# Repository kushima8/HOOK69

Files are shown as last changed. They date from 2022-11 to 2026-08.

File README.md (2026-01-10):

# HOOK69
Keyboard that hooks up to LCD tablets

https://shop.yushakobo.jp/products/5657

FZYuu6GaUAAWrVO
FZYuvYvaIAIYb_v

## Build Guide

[ビルドガイド（日本語）](Documents/buildguide.md)
  
120px-Cc-by-nc-sa_icon svg

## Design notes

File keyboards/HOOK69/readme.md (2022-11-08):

# hook69

hook69

*A short description of the keyboard/project*

* Keyboard Maintainer: [kushima8](https://github.com/yourusername)
* Hardware Supported: *The PCBs, controllers supported*
* Hardware Availability: *Links to where you can find this hardware*

Make example for this keyboard (after setting up your build environment):

    make hook69:default

Flashing example for this keyboard:

    make hook69:default:flash

See the [build environment setup](https://docs.qmk.fm/#/getting_started_build_tools) and the [make instructions](https://docs.qmk.fm/#/getting_started_make_guide) for more information. Brand new to QMK? Start with our [Complete Newbs Guide](https://docs.qmk.fm/#/newbs).

## Bootloader

Enter the bootloader in 3 ways:

* **Bootmagic reset**: Hold down the key at (0,0) in the matrix (usually the top left key or Escape) and plug in the keyboard
* **Physical reset button**: Briefly press the button on the back of the PCB - some may have pads you must short instead
* **Keycode in layout**: Press the key mapped to `RESET` if it is available

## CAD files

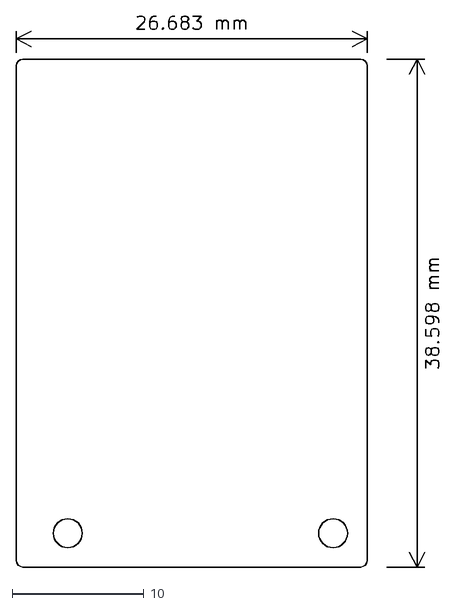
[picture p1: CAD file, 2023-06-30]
Plate/hook69_plate.dxf
32.1 x 41.9

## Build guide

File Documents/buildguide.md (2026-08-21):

# HOOK69 ビルドガイド

## ご購入前にお読みください

本製品をご購入いただいた時点で、下記「譲渡・再販について」の内容にご同意いただいたものとみなします。

### 譲渡・再販について

BOOTHや遊舎工房など、作者本人が販売または委託している場所以外で購入された場合、同梱品の不足や不良品への対応など、各種サポートをいたしかねます。  
そのため、以下のとおりお願いしております。

1. 本製品（完成品・未完成品・付属部品を問わず）を、ネットオークション、フリマサービス、その他の方法により第三者へ有償で譲渡することを禁止します。
2. 本項に反する行為を確認した場合、以後の販売をお断りする場合があります。

## はじめに
このたびはご購入いただきありがとうございます。  
本製品は組み立てが必要なキットです。  

作成にあたり不明点や疑問点などがありましたら、作者の[Twitterアカウント](https://twitter.com/kushima8)までご連絡ください。  
Twitter以外で連絡を頂いても対応が厳しいです。  
FF外からのリプライは通知オフにしており気づかない場合がこざいますご了承ください。  
それとDiscordのコミュニティなどで作者以外の方だけに不明点や疑問点などを質問することは非推奨です。  

HOOK69はTK様([@tnkzm_tk](https://twitter.com/tnkzm_tk))のアイディアを元に液晶タブレット上面に設置して使用することに主眼を置いたキーボードです。  
使用するキーキャップについては[キーレイアウト](https://www.keyboard-layout-editor.com/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,&=%3E%0A%0A%0A%0A%0A%0A.&=%3F%0A%0A%0A%0A%0A%0A%2F%2F&=%2F_%0A%0A%0A%0A%0A%0A%5C&=Fn&=Ctrl&=%E2%80%99%0A%0A%0A%0A%0A%0A7&=(%0A%0A%0A%0A%0A%0A8&=)%0A%0A%0A%0A%0A%0A9&=%E2%86%90&=%E2%86%93&=%E2%86%92&_x:0.75%3B&=Rotary%0A%0A%0A%0A%0A%0ADown)を確認してください。  

写真は作成見本であり商品内容と同一ではありません。  
また仕様は予告なく変更されることがあります。  

完成品、未完成品にかかわらずヤフオク!やメルカリなどのネットオークションやフリマなどでの販売、転売は禁止しております。  
Boothや遊舎工房など作者本人が販売または委託している箇所以外で購入された場合、同梱品の不足や不良品の対応などの各種サポートが厳しいためです。  
もし発見した場合は対応します。  
ご理解のほどよろしくお願いいたします。  

ファームウェアに[qmk_firmware](https://github.com/qmk/qmk_firmware)を採用しています。  
QMKにHOOK69のコードはまだマージされていませんのでこの[ブランチ](https://github.com/kushima8/qmk_firmware/tree/hook69)を使用してください。  
動作確認の為に[HEXファイル](https://github.com/kushima8/HOOK69/tree/main/HEX)を用意しています。  

キット作成前にPro Microの書き込み環境の構築を行ってください。  
ファームウェアの書き込み環境の構築については下記のサリチル酸さんのサイトを参考にしてください。  
[（初心者編）自作キーボードにファームウェアを書き込む](https://salicylic-acid3.hatenablog.com/entry/qmk-toolbox)  

キー割り当ての変更方法などはご自身でお調べいただくようお願いします。  

GUIから簡単にキー割り当てを変更できる[VIA](https://caniusevia.com/)と[Remap](https://remap-keys.app/)に対応しております。  
ロータリーエンコーダの回転割り当ても含め、設定できますのでご活用ください。  
VIAとRemapについては下記のサリチル酸さんのサイトを参考にしてください。  
[（初心者編）VIAを使ってキーマップを書き換えよう](https://salicylic-acid3.hatenablog.com/entry/via-manual)  
[（初心者編）Remapを使ってキーマップを書き換えよう](https://salicylic-acid3.hatenablog.com/entry/remap-manual)  

以下の部品リストを参考に欠品がないか確認をお願いします。  
欠品や不良品などがありましたら確認したのちに対応いたします。  
ただし、海外など発送が難しい場合はこちらの指定する方法での一部返金などで対応します。  
あらかじめご了承ください。  

## 部品

### キットに付属しているもの

|名称|数量|備考|
|----|:---:|----|
|PCB|1枚|リバーシブル|
|トッププレート|1枚||
|ボトムプレート|1枚||
|M2 6mmスペーサー(ARB-2006E)|14個|丸型両メネジ|
|M2 4mmネジ|16本|
|M2 6mmネジ|12本|
|Kailh PCB ソケット(Kailh Choc V1用)|69個|
|ダイオード(1N4148W)|82個|
|タクトスイッチ|1個|
|ミニブックエンド|2個|

### 別途、購入が必ず必要なもの
以下の部品は別途購入してください。

|名称|数量|備考|
|----|:---:|----|
|キースイッチ(Cherry MX互換 or Kailh Choc V1)|69個|
|キーキャップ(Cherry MX互換 or Kailh Choc V2)|69個|
|Pro Micro|1個||
|コンスルーピンヘッダ|2個|キットに同梱されてない場合|
|プッシュスイッチ内蔵ロータリーエンコーダ(EC11/EC12互換 or EVQWGD001)|1個|
|ノブ|1個|EC11/EC12互換使用の場合のみ|

### オプション
以下の部品はオプション品です。
キーボードを光らせたいなどの場合のみ別途購入してください。

|名称|数量|備考|
|----|:---:|----|
|LEDチップ(YS-SK6812MINI-E)|1個|
|OLEDモジュール|1個|
|OLED用ピンソケット|1個|
|Kailh PCB ソケット(Cherry MX互換用)|69個|
|M2 3.5mmスペーサー(ARB-2003.5E)|12個|全キーCherry MX互換使用時のみ|
|M2 8mmネジ|12個|全キーCherry MX互換使用時のみ|

## 組み立て
※Daihuku Keyboardさんによるビルド動画があります。  
　本機を作成するにあたって参考になると思いますので是非御覧ください。  
　自作キーボード作ってみた HOOK69編 (https://www.youtube.com/watch?v=qUh0zuOqxo4)  
※完成見本写真などではPro Microの接続位置を左端にしていますが、本機はリバーシブルPCBとなっております。  
　Pro Microを右端にして本機を使用したい場合は反転させて実装してください。  
　作成時にマスキングテープを使い表面と裏面がわかるようにしておくと作業ミスが少なくなります。  
　本ビルドガイドでは左側接続での作成での説明をしております。  
　右側接続で作成したい場合は適宜説明内容を読み替えてご覧ください。  
* 表面(左側接続)  
  
* 裏面(左側接続)  
  
* 表面(右側接続)  
  
* 裏面(右側接続)  
  
* 1.ヤスリがけ
  * 製造の都合上PCBにバリが存在します。  
  
  * バリが気になる場合は、この箇所を市販されている紙ヤスリなどで研磨してください。
* 2.Pro Microのはんだ付け
  * チップが載っている面が内側になるようにし、コンスルーピンヘッダを取り付けはんだ付けをしてください。
  * コンスルーピンヘッダには取り付け方向があるため気をつけてください。
  * [コンスルー - Self-Made Keyboards in Japan - ](https://scrapbox.io/self-made-kbds-ja/%E3%82%B3%E3%83%B3%E3%82%B9%E3%83%AB%E3%83%BC)  
  
* 3.ファームウェアの書き込み
  * 左側接続で作成したい場合は、[HOOK69_default.hex](https://github.com/kushima8/HOOK69/tree/main/HEX)を指定してファームウェアを書き込んでください。
  * 右側接続で作成したい場合は、[HOOK69_right.hex](https://github.com/kushima8/HOOK69/tree/main/HEX)を指定してファームウェアを書き込んでください。
  * [REMAP](https://remap-keys.app/catalog/6cgxsudKJEdLPk9axw0j/firmware)でもファームウェアを書き込めるようにしております。
  * PCBのProMicro取り付け位置は表側の長方形のシルクで囲まれている箇所です。
* 4.LEDチップのはんだ付け(オプション)
  * 高い温度ではんだ付けを行うとLED破損の可能性がありますので、約270℃に設定してはんだ付けをするようにしてください。
  * 基板裏面のGのシルクのマークの位置にLEDの足が欠けている箇所が来るように設置し、はんだ付けを行ってください。
  * はんだ付けが完了したら一度Pro Microを取り付け、LEDが光るかどうかテストを行ってください。  
  
  
* 5.ダイオードのはんだ付け
  * PCB裏面のダイオード取り付け箇所の片側に予めはんだを盛ります。  
  
  
  * その後、線が書いてある方を右(三角形の頂点の先に縦棒がある方)にセットします。
  * ダイオードをピンセットで持ちつつ、予めはんだを盛った箇所をはんだごてで加熱して片側だけはんだ付けを行います。  
  
  * 片側のはんだ付けが完了後、もう片方もはんだ付けを行ってください。  
  
* 6.Kailh PCB ソケット(MX用 or Kailh Choc V1用)のはんだ付け
  * PCB裏面のソケット取り付け箇所に予めはんだを盛ります。
  * 上穴がMX用で下穴がKailh Choc V1用です。  
  
  * 中央の穴に干渉しないようにソケットをPCB裏面に設置しはんだ付けを行ってください。  
  
  
  
* 7.タクトスイッチはんだ付け
  * PCB表面から取り付け、裏面からはんだ付けを行ってください。  
  
  
* 8.OLEDの取り付け(オプション)
  * PCB裏面にあるジャンパ4箇所をショートさせてください。  
  
  
  * OLEDモジュールとピンヘッダのハンダ付けを行ってください。
  * ピンソケットをPCB表面から取り付け、裏面からはんだ付けを行ってください。  
  
  
  
* 9.ロータリーエンコーダ(EC11/EC12互換 or EVQWGD001)のはんだ付け
  * PCB表面からロータリーエンコーダを取り付け、裏面からはんだ付けを行ってください。
  * EVQWGD001の取り付けはフックを右側に、ピンを左側にして実装してください。
  * 長方形の穴にフック側を差し込み引っ掛けてからピンをPCB側に刺すと取り付け出来ます。  
  
  
  
  
  * EC11/EC12互換の場合は表面から取り付け裏面からはんだ付けを行ってください。
  * PCBの都合上固定がしにくくなっておりますので、しっかりと固定するようにはんだ付けをしてください。  
  
  
* 10.キースイッチの取り付け
  * トッププレートの穴にキースイッチを取り付けてください。
  * キースイッチがハマりにくい場合はヤスリなどを使いトッププレートの穴を削ってください。  
  
  
* 11.トッププレートの取り付け
  * PCBとネジ穴とキースイッチが合うようにトッププレートをPCB表面に設置。
  * ネジ穴下部にM2 6mmスペーサーを置き、上部からM2 6mmネジで固定してください。  
  
  
* 12.ProMicro下部スペーサー取り付け
  * ProMicro下部のネジ穴下部にM2 6mmスペーサーを設置し、上面からM2 4mmネジで固定してください。  
  
  
* 13.ボトムプレートの取り付け。
  * スペーサーとボトムプレートのネジ穴の位置を合わせ、M2 4mmネジで固定してください。  
  
* 14.Pro Microの取り付け
  * Pro Microを取り付け、PCと接続しREMAPなどを用いてキースイッチとロータリーエンコーダの入力の確認を行ってください。
  * PCBのProMicro取り付け位置は表側の長方形のシルクで囲まれている箇所です。
  * REMAPなどでの押し込みを含めたロータリーエンコーダの割当は一列空白を開けた右端3つになります。
  * こちらが準備しているファームウェアの場合ロータリーエンコーダの割当が空ですので、REMAPなどで何かしらのキーを割当をしてから確認を行ってください。
rotaryencoder
* 15.OLEDモジュールの取り付け(オプション)
  * OLEDモジュールを取り付け、PCと接続し、表示されることの確認を行ってください。
  * デフォルトではレイヤーとLEDの光度情報が表示されます。
* 16.つまみの取り付け(EC11/EC12互換使用の場合のみ)
  * つまみをロータリーエンコーダーに取り付けてください。
* 17.キーキャップの取り付け
  * キースイッチにキーキャップを取り付けてください。
  * 使用するキーキャップはすべて1Uのものになります。
* 18.ブックエンドの取り付け
  * 液タブの上面に取り付けるためにブックエンドを背面に取り付けます。
  * 付属のブックエンドを配置したい液タブ上面の形状に合わせて折り曲げます。  
  
  
  
  
  * マスキングテープなどを使いキーボード本体に仮止めし、液タブ上面に設置します。  
  
　
　
  * 設置しブックエンドの配置に問題なければに仮止めを外し、両面テープなどで固定してください。
  * 固定する際はネジを避けるようにしてください。

組み立ての手順は、以上です。

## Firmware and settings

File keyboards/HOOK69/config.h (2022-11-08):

/*
Copyright 2022 kushima8

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
You should have received a copy of the GNU General Public License
along with this program.  If not, see <http://www.gnu.org/licenses/>.
*/

#pragma once

#include "config_common.h"

/* USB Device descriptor parameter */
#define VENDOR_ID    0x3938
#define PRODUCT_ID   0x3639
#define DEVICE_VER   0x0001
#define MANUFACTURER kushima8
#define PRODUCT      HOOK69

/* key matrix size */
#define MATRIX_ROWS 12
#define MATRIX_COLS 6

/*
 * Keyboard Matrix Assignments
 *
 * Change this to how you wired your keyboard
 * COLS: AVR pins used for columns, left to right
 * ROWS: AVR pins used for rows, top to bottom
 * DIODE_DIRECTION: COL2ROW = COL = Anode (+), ROW = Cathode (-, marked on diode)
 *                  ROW2COL = ROW = Anode (+), COL = Cathode (-, marked on diode)
 *
 */
#define MATRIX_ROW_PINS { D4, C6, D7, E6, B4, B5 }
#define MATRIX_COL_PINS { F4, F5, F6, F7, B1, B3 }
//#define UNUSED_PINS

/* COL2ROW, ROW2COL */
//#define DIODE_DIRECTION COL2ROW
//#define DIODE_DIRECTION CUSTOM_MATRIX
/*
 * Split Keyboard specific options, make sure you have 'SPLIT_KEYBOARD = yes' in your rules.mk, and define SOFT_SERIAL_PIN.
 */
#define SOFT_SERIAL_PIN D2  // or D1, D2, D3, E6

/* Rotary encoder define*/
#define ENCODERS_PAD_A { B2 }
#define ENCODERS_PAD_B { B6 }
//#define ENCODER_RESOLUTION 2

//#define LED_NUM_LOCK_PIN B0
//#define LED_CAPS_LOCK_PIN B1
//#define LED_SCROLL_LOCK_PIN B2
//#define LED_COMPOSE_PIN B3
//#define LED_KANA_PIN B4

//#define BACKLIGHT_PIN B7
//#define BACKLIGHT_LEVELS 3
//#define BACKLIGHT_BREATHING

#define RGB_DI_PIN D3
#ifdef RGB_DI_PIN
#    define RGBLED_NUM 1
//#    define RGBLIGHT_HUE_STEP 8
//#    define RGBLIGHT_SAT_STEP 8
//#    define RGBLIGHT_VAL_STEP 8
//#    define RGBLIGHT_LIMIT_VAL 255 /* The maximum brightness level */
//#    define RGBLIGHT_SLEEP  /* If defined, the RGB lighting will be switched off when the host goes to sleep */
/*== all animations enable ==*/
//#    define RGBLIGHT_ANIMATIONS
/*== or choose animations ==*/
//#    define RGBLIGHT_EFFECT_BREATHING
//#    define RGBLIGHT_EFFECT_RAINBOW_MOOD
//#    define RGBLIGHT_EFFECT_RAINBOW_SWIRL
//#    define RGBLIGHT_EFFECT_SNAKE
//#    define RGBLIGHT_EFFECT_KNIGHT
//#    define RGBLIGHT_EFFECT_CHRISTMAS
//#    define RGBLIGHT_EFFECT_STATIC_GRADIENT
//#    define RGBLIGHT_EFFECT_RGB_TEST
//#    define RGBLIGHT_EFFECT_ALTERNATING
/*== customize breathing effect ==*/
/*==== (DEFAULT) use fixed table instead of exp() and sin() ====*/
//#    define RGBLIGHT_BREATHE_TABLE_SIZE 256      // 256(default) or 128 or 64
/*==== use exp() and sin() ====*/
//#    define RGBLIGHT_EFFECT_BREATHE_CENTER 1.85  // 1 to 2.7
//#    define RGBLIGHT_EFFECT_BREATHE_MAX    255   // 0 to 255
#endif

/* Debounce reduces chatter (unintended double-presses) - set 0 if debouncing is not needed */
#define DEBOUNCE 5

/* define if matrix has ghost (lacks anti-ghosting diodes) */
//#define MATRIX_HAS_GHOST

/* Mechanical locking support. Use KC_LCAP, KC_LNUM or KC_LSCR instead in keymap */
#define LOCKING_SUPPORT_ENABLE
/* Locking resynchronize hack */
#define LOCKING_RESYNC_ENABLE

/* If defined, GRAVE_ESC will always act as ESC when CTRL is held.
 * This is useful for the Windows task manager shortcut (ctrl+shift+esc).
 */
//#define GRAVE_ESC_CTRL_OVERRIDE

/*
 * Force NKRO
 *
 * Force NKRO (nKey Rollover) to be enabled by default, regardless of the saved
 * state in the bootmagic EEPROM settings. (Note that NKRO must be enabled in the
 * makefile for this to work.)
 *
 * If forced on, NKRO can be disabled via magic key (default = LShift+RShift+N)
 * until the next keyboard reset.
 *
 * NKRO may prevent your keystrokes from being detected in the BIOS, but it is
 * fully operational during normal computer usage.
 *
 * For a less heavy-handed approach, enable NKRO via magic key (LShift+RShift+N)
 * or via bootmagic (hold SPACE+N while plugging in the keyboard). Once set by
 * bootmagic, NKRO mode will always be enabled until it is toggled again during a
 * power-up.
 *
 */
//#define FORCE_NKRO

/*
 * Feature disable options
 *  These options are also useful to firmware size reduction.
 */

/* disable debug print */
//#define NO_DEBUG

/* disable print */
//#define NO_PRINT

/* disable action features */
//#define NO_ACTION_LAYER
//#define NO_ACTION_TAPPING
//#define NO_ACTION_ONESHOT

/* disable these deprecated features by default */
//#define NO_ACTION_MACRO
//#define NO_ACTION_FUNCTION

/* Bootmagic Lite key configuration */
//#define BOOTMAGIC_LITE_ROW 0
//#define BOOTMAGIC_LITE_COLUMN 0

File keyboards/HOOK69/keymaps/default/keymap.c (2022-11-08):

/* Copyright 2022 kushima8
 *
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
 * You should have received a copy of the GNU General Public License
 * along with this program.  If not, see <http://www.gnu.org/licenses/>.
 */
#include <stdio.h>
#include QMK_KEYBOARD_H
#include "keymap_japanese.h"

// Defines names for use in layer keycodes and the keymap
enum layer_names {
     _1st,
     _2nd,
     _3rd,
     _4th
};

const uint16_t PROGMEM keymaps[][MATRIX_ROWS][MATRIX_COLS] = {
     [_1st] = LAYOUT(
     // ,--------+--------+--------+--------+--------+--------+--------+--------+--------+--------+--------+--------+--------+--------+--------+--------+--------+--------+--------+--------+--------+--------+--------+--------.
        KC_ESC   ,JP_ZKHK ,KC_Q    ,KC_W    ,KC_E    ,KC_R    ,KC_T    ,KC_Y    ,KC_SPC  ,KC_U    ,KC_I    ,KC_O    ,KC_P    ,JP_AT   ,JP_LBRC ,KC_RGUI ,KC_BSPC ,KC_1    ,KC_2    ,KC_3    ,KC_0    ,JP_MINS ,JP_CIRC ,KC_Z    ,
     // |--------+--------+--------+--------+--------+--------+--------+--------+--------+--------+--------+--------+--------+--------+--------+--------+--------+--------+--------+--------+--------+--------+--------+--------|
        KC_TAB   ,KC_LSFT ,KC_A    ,KC_S    ,KC_D    ,KC_F    ,KC_G    ,KC_H    ,KC_SPC  ,KC_J    ,KC_K    ,KC_L    ,JP_SCLN ,JP_COLN ,JP_RBRC ,KC_RSFT ,KC_ENT  ,KC_4    ,KC_5    ,KC_6    ,KC_A    ,KC_UP   ,KC_B    ,
     // |--------+--------+--------+--------+--------+--------+--------+--------+--------+--------+--------+--------+--------+--------+--------+--------+--------+--------+--------+--------+--------+--------+--------+--------|
        KC_CAPS  ,KC_LCTRL,KC_LALT ,KC_Z    ,KC_X    ,KC_C    ,KC_V    ,KC_B    ,KC_SPC  ,KC_N    ,KC_M    ,KC_COMM ,KC_DOT  ,KC_SLSH ,JP_BSLS ,KC_Z    ,KC_RCTRL,KC_7    ,KC_8    ,KC_9    ,KC_LEFT ,KC_DOWN ,KC_RIGHT
     // `--------+--------+--------+--------+--------+--------+--------+--------+--------+--------+--------+--------+--------+--------+--------+--------+--------+--------+--------+--------+--------+--------+--------+--------'
     ),
     [_2nd] = LAYOUT(
     // ,--------+--------+--------+--------+--------+--------+--------+--------+--------+--------+--------+--------+--------+--------+--------+--------+--------+--------+--------+--------+--------+--------+--------+--------.
        KC_ESC   ,JP_ZKHK ,KC_Q    ,KC_W    ,KC_E    ,KC_R    ,KC_T    ,KC_Y    ,KC_SPC  ,KC_U    ,KC_I    ,KC_O    ,KC_P    ,JP_AT   ,JP_LBRC ,KC_RGUI ,KC_BSPC ,KC_1    ,KC_2    ,KC_3    ,KC_0    ,JP_MINS ,JP_CIRC ,KC_Z    ,
     // |--------+--------+--------+--------+--------+--------+--------+--------+--------+--------+--------+--------+--------+--------+--------+--------+--------+--------+--------+--------+--------+--------+--------+--------|
        KC_TAB   ,KC_LSFT ,KC_A    ,KC_S    ,KC_D    ,KC_F    ,KC_G    ,KC_H    ,KC_SPC  ,KC_J    ,KC_K    ,KC_L    ,JP_SCLN ,JP_COLN ,JP_RBRC ,KC_RSFT ,KC_ENT  ,KC_4    ,KC_5    ,KC_6    ,KC_A    ,KC_UP   ,KC_B    ,
     // |--------+--------+--------+--------+--------+--------+--------+--------+--------+--------+--------+--------+--------+--------+--------+--------+--------+--------+--------+--------+--------+--------+--------+--------|
        KC_CAPS  ,KC_LCTRL,KC_LALT ,KC_Z    ,KC_X    ,KC_C    ,KC_V    ,KC_B    ,KC_SPC  ,KC_N    ,KC_M    ,KC_COMM ,KC_DOT  ,KC_SLSH ,JP_BSLS ,KC_Z    ,KC_RCTRL,KC_7    ,KC_8    ,KC_9    ,KC_LEFT ,KC_DOWN ,KC_RIGHT
     // `--------+--------+--------+--------+--------+--------+--------+--------+--------+--------+--------+--------+--------+--------+--------+--------+--------+--------+--------+--------+--------+--------+--------+--------'
     ),
     [_3rd] = LAYOUT(
     // ,--------+--------+--------+--------+--------+--------+--------+--------+--------+--------+--------+--------+--------+--------+--------+--------+--------+--------+--------+--------+--------+--------+--------+--------.
        KC_ESC   ,JP_ZKHK ,KC_Q    ,KC_W    ,KC_E    ,KC_R    ,KC_T    ,KC_Y    ,KC_SPC  ,KC_U    ,KC_I    ,KC_O    ,KC_P    ,JP_AT   ,JP_LBRC ,KC_RGUI ,KC_BSPC ,KC_1    ,KC_2    ,KC_3    ,KC_0    ,JP_MINS ,JP_CIRC ,KC_Z    ,
     // |--------+--------+--------+--------+--------+--------+--------+--------+--------+--------+--------+--------+--------+--------+--------+--------+--------+--------+--------+--------+--------+--------+--------+--------|
        KC_TAB   ,KC_LSFT ,KC_A    ,KC_S    ,KC_D    ,KC_F    ,KC_G    ,KC_H    ,KC_SPC  ,KC_J    ,KC_K    ,KC_L    ,JP_SCLN ,JP_COLN ,JP_RBRC ,KC_RSFT ,KC_ENT  ,KC_4    ,KC_5    ,KC_6    ,KC_A    ,KC_UP   ,KC_B    ,
     // |--------+--------+--------+--------+--------+--------+--------+--------+--------+--------+--------+--------+--------+--------+--------+--------+--------+--------+--------+--------+--------+--------+--------+--------|
        KC_CAPS  ,KC_LCTRL,KC_LALT ,KC_Z    ,KC_X    ,KC_C    ,KC_V    ,KC_B    ,KC_SPC  ,KC_N    ,KC_M    ,KC_COMM ,KC_DOT  ,KC_SLSH ,JP_BSLS ,KC_Z    ,KC_RCTRL,KC_7    ,KC_8    ,KC_9    ,KC_LEFT ,KC_DOWN ,KC_RIGHT
     // `--------+--------+--------+--------+--------+--------+--------+--------+--------+--------+--------+--------+--------+--------+--------+--------+--------+--------+--------+--------+--------+--------+--------+--------'
     ),
     [_4th] = LAYOUT(
     // ,--------+--------+--------+--------+--------+--------+--------+--------+--------+--------+--------+--------+--------+--------+--------+--------+--------+--------+--------+--------+--------+--------+--------+--------.
        KC_ESC   ,JP_ZKHK ,KC_Q    ,KC_W    ,KC_E    ,KC_R    ,KC_T    ,KC_Y    ,KC_SPC  ,KC_U    ,KC_I    ,KC_O    ,KC_P    ,JP_AT   ,JP_LBRC ,KC_RGUI ,KC_BSPC ,KC_1    ,KC_2    ,KC_3    ,KC_0    ,JP_MINS ,JP_CIRC ,KC_Z    ,
     // |--------+--------+--------+--------+--------+--------+--------+--------+--------+--------+--------+--------+--------+--------+--------+--------+--------+--------+--------+--------+--------+--------+--------+--------|
        KC_TAB   ,KC_LSFT ,KC_A    ,KC_S    ,KC_D    ,KC_F    ,KC_G    ,KC_H    ,KC_SPC  ,KC_J    ,KC_K    ,KC_L    ,JP_SCLN ,JP_COLN ,JP_RBRC ,KC_RSFT ,KC_ENT  ,KC_4    ,KC_5    ,KC_6    ,KC_A    ,KC_UP   ,KC_B    ,
     // |--------+--------+--------+--------+--------+--------+--------+--------+--------+--------+--------+--------+--------+--------+--------+--------+--------+--------+--------+--------+--------+--------+--------+--------|
        KC_CAPS  ,KC_LCTRL,KC_LALT ,KC_Z    ,KC_X    ,KC_C    ,KC_V    ,KC_B    ,KC_SPC  ,KC_N    ,KC_M    ,KC_COMM ,KC_DOT  ,KC_SLSH ,JP_BSLS ,KC_Z    ,KC_RCTRL,KC_7    ,KC_8    ,KC_9    ,KC_LEFT ,KC_DOWN ,KC_RIGHT
     // `--------+--------+--------+--------+--------+--------+--------+--------+--------+--------+--------+--------+--------+--------+--------+--------+--------+--------+--------+--------+--------+--------+--------+--------'
     )
};

#ifdef ENCODER_ENABLE

/* Rotary encoder settings */

keyevent_t encoder_ccw  = {
     .key = (keypos_t){.row = 5, .col = 5},
     .pressed = false
};
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

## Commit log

2023-06-30 add plate
    [hook69_plate.dxf]
2026-01-07 ADD HEX UF2 STL
    [hook49case.stl, hook49・64_plate.stl, hook64case.stl]

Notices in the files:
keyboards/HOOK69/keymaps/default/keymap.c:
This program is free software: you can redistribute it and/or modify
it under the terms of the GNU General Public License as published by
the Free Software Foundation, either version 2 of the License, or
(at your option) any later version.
